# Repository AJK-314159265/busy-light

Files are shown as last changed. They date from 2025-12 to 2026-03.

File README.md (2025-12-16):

# Busy Light (Outlook → NeoPixel) — Local‑Only Project

Turn your Outlook calendar on Windows into a **busy light** driven by a single **WS2812/NeoPixel** LED over serial.  
Privacy-first: No Azure. No Graph. No Teams. **Local-only**: Outlook COM + Serial.

This repo contains everything: **Python GUI app**, **Arduino firmware**, **electronics notes**, and **3D-printed housing** guidelines.

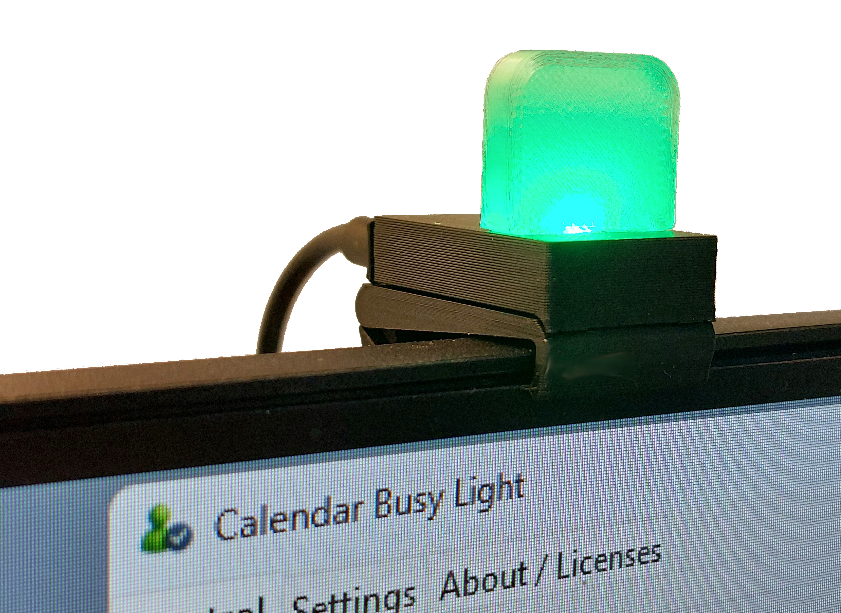
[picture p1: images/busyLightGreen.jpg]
BusyLightGreen


## Highlights

- **Windows Python GUI** reads your **local Outlook** calendar via COM
- **Arduino NeoPixel** firmware accepts `R G B` commands over serial
- **Heartbeat auto‑off**: light turns off if host goes away (no `PING`)
- **Configurable colors**, brightness, fade, blink, working hours
- **Manual mode** + **Quick test** buttons for instant checks
- **3D-printable housing** STEP files and printing suggestions

> Privacy by design: no cloud tokens, no tenant approval, no Graph calls—just your local Outlook app and a serial cable.

## Repository Structure

```text
.
├─ arduino/
│  ├─ busylight/busylight.ino # firmware for WS2812/NeoPixel
│  └─ README.md                               # Arduino-specific docs
├─ python/
│  ├─ assets/                                 # icons images
│  ├─ calendar_busy_light.py                  # main GUI app
│  └─ README.md                               # Python-specific docs
├─ hardware/
│  └─ README.md                               # (optional) detailed wiring notes
├─ housing/
│  ├─ step/                                   # STEP files
│  │  ├─ Light_Guide.step
│  │  ├─ Mounting_bracket.step
│  │  ├─ PCB_case_usb_c.step
│  │  ├─ PCB_case_back_c.step
│  │  ├─ PCB_case_micro_usb.step
│  │  └─ PCB_case_back_micro_usb.step
│  └─ README.md                               # printer settings & assembly
├─ images/
├─ LICENSE.md
└─ README.md                                  # ← this file
```

## System Overview

```text
Outlook (Windows) ──COM──► Python GUI ──Serial(115200)──► Arduino ──► NeoPixel LED
                                 ▲             │
                                 └── Heartbeat ┘  (PING/PONG; auto‑off on timeout)
```

### Status Mapping (default)

| Calendar status | LED behavior (configurable) |
| --- | --- |
| **Busy / Tentative** | Red |
| **Upcoming Busy** (N min before) | Blinking orange |
| **OOF** | Off |
| **Free / Working Elsewhere** | Green |

Everything is configurable in the GUI and saved to JSON.

## Electronics

The electronics are based on a **Pro Micro — 5 V / 16 MHz board** with a single **WS2812B** addressable RGB LED mounted on the back.

- 1× **Pro Micro — 5 V / 16 MHz** (ATmega32U4)
- 1× **WS2812B** addressable RGB LED (single LED)
- 1 × USB-C or Micro-USB cable (depending on the USB connector type of the selected Pro Micro board)

> See [**./hardware/README.md**](./hardware/README.md) for full details.

## Arduino Firmware

- File: [./arduino/busylight/busylight.ino](./arduino/busylight/busylight.ino)
- Library: **Adafruit NeoPixel** (via Library Manager)
- Baud: **115200**

### Supported Commands

- Color: `255 0 0` / `RGB 0 255 0` / `#FF8000`
- Utility: `OFF`, `TEST`
- Heartbeat: `PING` → replies `PONG`
- Watchdog config: `HBEN 0/1`, `HBTO <ms>`, `HBRST`, `STAT?`

On boot, the LED briefly blinks gray to show the firmware is running.  
If **no `PING`** is received for the configured timeout, the LED turns **off** automatically.

> See [**./arduino/README.md**](./arduino/README.md) for full details.

## Python GUI App

- File: [./python/calendar_busy_light.py](./python/calendar_busy_light.py)
- Requires: `pywin32`, `pyserial`

  ```bash
  pip install pywin32 pyserial
  ```

- Run:

  ```bash
  pythonw.exe python/calendar_busy_light.py
  ```

> See [**./windows_startup_python_guide.md**](./windows_startup_python_guide.md) for details on how to configure Windows 11 to automatically run a the Python application at startup.

### Key Features

- **Auto/Manual** mode toggle
- **Color scheme** pickers (Busy, Upcoming, Free, OOF, Unknown)
- **Brightness** (0–100%), **Fade** (ms)
- **Upcoming window** (min), **Past grace** (min)
- **Ignore subjects** (e.g., `lunch; focus; reminder`)
- **Working hours** + out‑of‑hours status behavior
- **Progress bar** and **countdown** to start/end
- **Heartbeat & ACK** (enable, interval, expect ACK, timeout)
- **Serial auto‑reconnect** and **Quick test** buttons
- **JSON settings** persisted (no registry edits)

> See [**./python/README.md**](./python/README.md) for full details.

## Housing (3D‑Printed)

The STEP files are located in the 'housing/step/' directory:

- Light_Guide.step - Translucent cap above the NeoPixel
- Mounting_bracket.step - Monitor mounting bracket
- PCB_case.step - Enclosure for the Pro Micro board with the single LED
- PCB_case_back.step - Back cover of the enclosure with slots for the USB connector

> See [**./housing/README.md**](./housing/README.md) for full details.

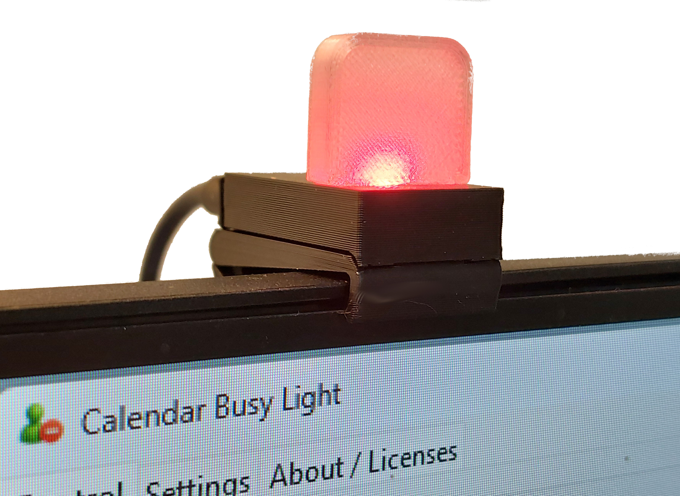
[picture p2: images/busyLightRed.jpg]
BusyLightRed


### Assembly Tips

1. Attach the LED to the back of the main PCB.
2. Route the D4, GND, and 5V wires to the LED PCB, keeping the wires as short as possible.
3. Slide the PCB into the **PCB case** with the LED facing the light opening.
4. Press-fit the **PCB case back** (back cover) over the USB plug.
5. Slide the PCB case assembly onto the mounting bracket.
6. Press-fit the **Light Guide** (diffuser) on top of the enclosure.
7. Plug in the USB cable and verify operation using the Python **Quick Test**.

See [**./hardware/README.md**](./hardware/README.md) and [**./housing/README.md**](./housing/README.md) for full details.

## Quick Start (End‑to‑End)

1. **Flash Arduino** with `NeoPixelBusyLight.ino` and verify via Serial Monitor:
   - `TEST` cycles colors, `PING` → `PONG`.
2. **Run Python app**, pick your **COM port** in *Settings → Serial*, and **Save settings**.
3. Click **Manual → Free** to verify LEDs.
4. Switch to **Auto**: your Outlook calendar should now drive the light.

## Troubleshooting

- **No light but PONG works**:
  - Check **Brightness > 0%**, **Color scheme** for current state, and **Out‑of‑hours** behavior.
- **No serial**: ensure only one app owns the COM port (close Serial Monitor).
- **Blink looks dim**: reduce **Fade** (ms) or set to **0** for hard edges.
- **Turns off randomly**: heartbeat watchdog timed out—either increase `HBTO` (firmware) or ensure the Python heartbeat interval is smaller than the timeout.

## License

This project is released as open-source software under the [MIT License](../LICENSE.md), Copyright (c) 2025 Allan Juhl Kristensen

The software is provided “as is,” without any express or implied warranty.

## Credits

- Adafruit NeoPixel library
- `pywin32`, `pyserial`

Happy making! 🎉

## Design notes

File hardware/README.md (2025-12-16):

# Busy Light Electronics

The Busy Light hardware is based on a **Pro Micro (ATmega32U4)**. The USB transceiver is integrated into the ATmega32U4, so the board provides native USB connectivity without the need for external interface components. The Pro Micro is available in both 3.3 V and 5 V variants; for this project, the **5 V / 16 MHz** version must be used.

Please note that many Pro Micro clones are available on the market. Ensure that the selected board matches the required enclosure dimensions of about **36 × 18 mm**.

## Electronics

### Bill of Materials (BOM)

- 1× **Pro Micro — 5 V / 16 MHz** (ATmega32U4)
- 1× **WS2812B** addressable RGB LED (single LED)
- 1 × USB-C or Micro-USB cable (depending on the USB connector type of the selected Pro Micro board)

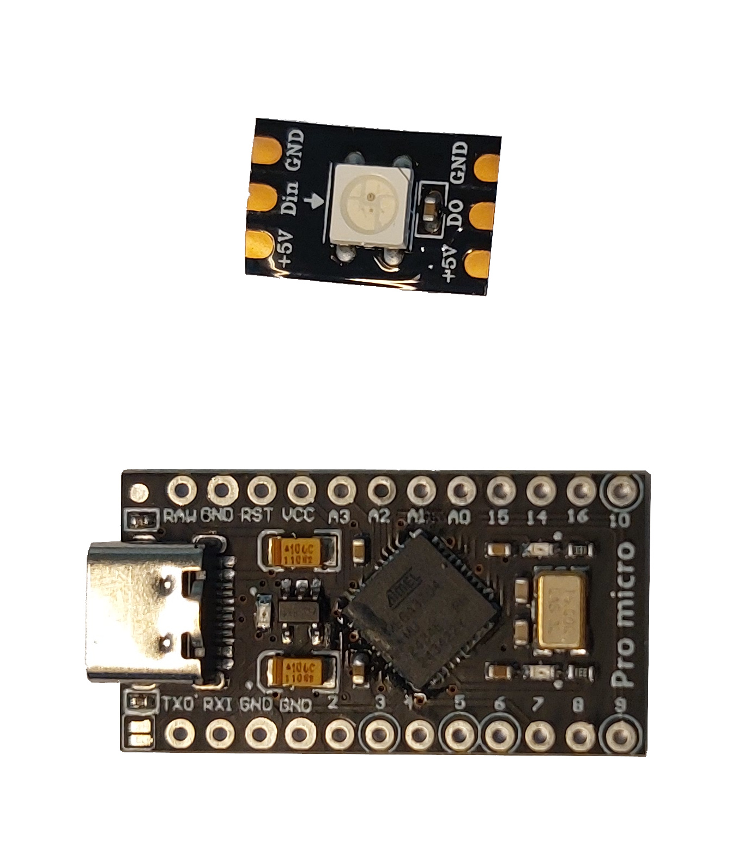
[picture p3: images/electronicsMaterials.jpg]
Materials


### Wiring (single LED)

```text
Pro Micro 5V  ──► WS2812B LED 5V
Pro Micro GND ──► WS2812B LED GND
Pro Micro D4  ──► WS2812B LED DIN
```

- Make sure the Pro Micro D4 gos to WS2812B LED **DIN** and not to WS2812B LED **DO**.
- Keep **GND common** between the Pro Micro and the LED.
- Data pin default in the firmware is **D4**; you can change it in the sketch if needed.
- With **~15 mm** data wire and **one LED**, direct wiring is fine.
- A single WS2812 at full white draws **≤60 mA** - USB can easily supply that.

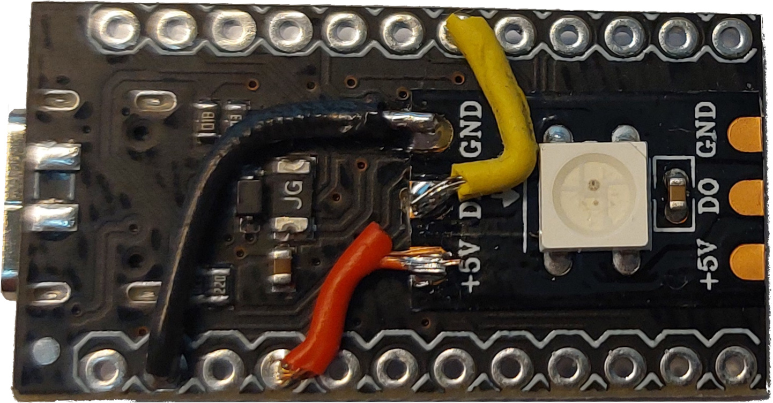
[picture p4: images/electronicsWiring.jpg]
Wiring


## Firmware Notes (Arduino)

For information on the Firmware see: [../arduino/README.md](../arduino/README.md)

## Reference & Datasheets

- [Pro Micro pinout](https://salt.tikicdn.com/ts/product/43/26/b9/10e6217f0be0510c92a05691e59fac0f.png)
- [ATmega32U4 datasheet](https://ww1.microchip.com/downloads/en/DeviceDoc/Atmel-7766-8-bit-AVR-ATmega16U4-32U4_Datasheet.pdf)
- [Pro Micro Schematic](https://cdn.sparkfun.com/datasheets/Dev/Arduino/Boards/Pro_Micro_v13b.pdf)

## License Information

This project is released as open-source software under the [MIT License](../LICENSE.md), Copyright (c) 2025 Allan Juhl Kristensen

The software is provided “as is,” without any express or implied warranty.

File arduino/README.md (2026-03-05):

# NeoPixel Busy Light (Serial + Heartbeat Auto-Off)

A tiny Arduino firmware that turns a single **WS2812 / NeoPixel** LED into a presence/busy indicator controllable over **serial**.

- Accepts simple commands like `255 0 0`, `RGB 0 255 0`, `#FF8000`, `OFF`, `TEST`.
- Responds to `PING` with `PONG` (for host health checks).
- **Auto-off** if no heartbeat (`PING`) is received for a configurable timeout.

> ⚠️ Note: Some call these LEDs “WLED”, but this sketch is for **WS2812/NeoPixel** hardware using the **Adafruit NeoPixel** library—not the WLED firmware project.

## Features

- Simple serial protocol (human-readable).
- Heartbeat watchdog: turns LED off if host disappears.
- Built-in test pattern.
- Works with any board supported by Adafruit NeoPixel (Uno, Nano, Leonardo, etc.).
- Pairs nicely with a Python GUI / status app (e.g., calendar/Teams presence).

## Hardware

For information on the Hardware see: [../hardware/README.md](../hardware/README.md)

## Getting Started (one-time setup)

1. **Install Arduino IDE** (latest).
2. **Install library**: *Tools → Manage Libraries…* → search **“Adafruit NeoPixel”** → Install.
3. Go to **File → Preferences**
4. In “**Additional Boards Manager URLs**”, add this URL (add a comma if others already exist):

   ```txt
   https://raw.githubusercontent.com/sparkfun/Arduino_Boards/master/IDE_Board_Manager/package_sparkfun_index.json
   ```

5. Click OK
6. Go to Tools → Board → Boards Manager…
7. Search for “SparkFun AVR Boards”
8. Click Install

## Select the correct board every time

1. Plug the board into USB
2. In Arduino IDE, select:
   - **Tools → Board → SparkFun AVR Boards → SparkFun Pro Micro**
   - **Tools → Processor → ATmega32U4 (5V, 16MHz)** 
   - **Tools → Port** → select the COM port that appears when you plug in the board

   > ⚠️ **Important:** Never change **Processor** to 3.3V/8MHz for these boards – that’s what breaks USB.

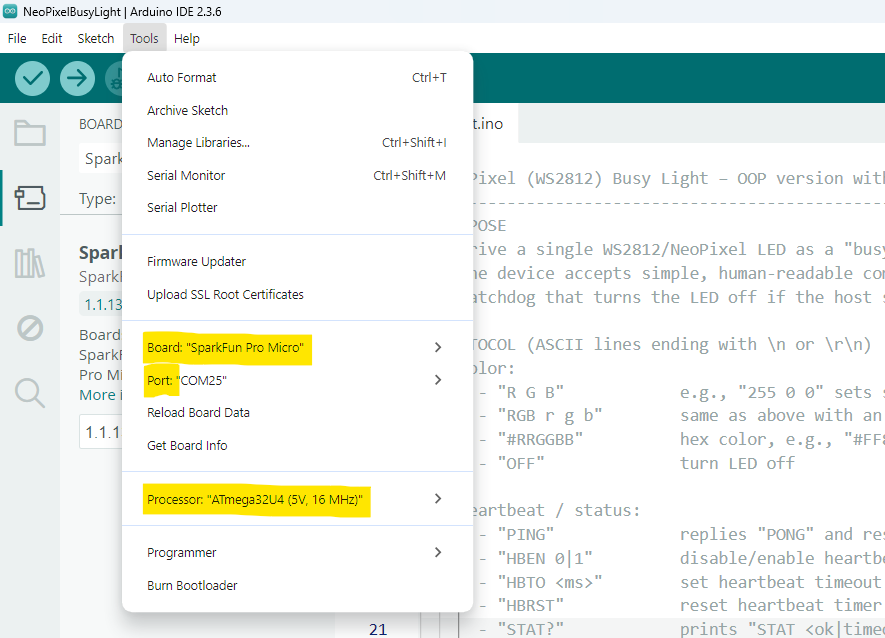
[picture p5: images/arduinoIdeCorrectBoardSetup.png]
Correct Board Setup
   

3. **Open** the sketch (`busylight.ino`) in Arduino IDE.
4. (Optional) Edit these lines if needed:

   ```cpp
   #define LED_PIN    4        // data pin to your NeoPixel
   #define NUM_LEDS   1        // number of LEDs in your strip
   #define BAUD       115200   // must match your host app
   // Heartbeat defaults:
   #define HB_DEFAULT_ENABLED     1
   #define HB_DEFAULT_TIMEOUT_MS  25000UL
   ```

5. Click Upload (the right-arrow button)
6. Wait for “Done uploading.” at the bottom
7. Open **Serial Monitor** @ **115200** and try:
   - `TEST` → cycles colors  
   - `255 255 255` → white  
   - `PING` → prints `PONG`

## Serial Protocol

| Command | Description | Example | Response |
|---|---|---|---|
| `R G B` | Set color (0–255 per channel) | `255 0 0` | – |
| `RGB r g b` | Same as above with `RGB` prefix | `RGB 0 255 0` | – |
| `#RRGGBB` | Hex color | `#FF8000` | – |
| `OFF` | Turn LED off | `OFF` | – |
| `TEST` | Cycle R→G→B→White→Off | `TEST` | – |
| `PING` | Heartbeat ping | `PING` | `PONG` |
| `HBEN 0/1`  | Disable/enable heartbeat watchdog | `HBEN 1` | `HBEN=1` |
| `HBEN?` | Report heartbeat watchdog disable/enable status | `HBEN?` | `HBEN=1` |
| `HBTO <ms>` | Set heartbeat timeout (milliseconds) | `HBTO 25000` | `HBTO=25000` |
| `HBRST` | Reset heartbeat timer | `HBRST` | `HBRST=OK` |
| `STAT?` | Report status & current RGB | `STAT?` | `STAT=OK; RGB=0 0 0` |
| `VER?` | Report firmware version and build date/time | `VER?` | `VER=1.0.0; BUILD=2026-01-05 22:03:00` |

**Behavior:**  
If `HBEN` is on (default) and **no `PING`** arrives within `HBTO` ms, the LED is **forced OFF** until a new `PING` (or color command) is received.

## Example Sessions

**Manual testing in Serial Monitor:**

```txt
> TEST
> 255 0 0
> 0 255 0
> #0000FF
> OFF
> PING
PONG
> STAT?
STAT ok RGB 0 0 0
```

**Host heartbeat rhythm**  
If your host sends `PING` every 10 s, set timeout to something like 25 s:

```txt
> HBTO 25000
HBTO=25000
> HBEN 1
HBEN=1
```

## Integrating with a Host App

- Open the COM port at **115200** baud.
- Send color lines as ASCII with a trailing newline, e.g.:

```txt
  "255 128 0\n"
  "PING\n"
```

- If you enable ACK checking in the host, read lines and look for **`PONG`**.
- Keep your heartbeat **interval < timeout** (e.g., interval 10 s, timeout 25 s).

---

## Troubleshooting

- **No light at all**
  - Verify 5V/GND, data pin, and that the **NeoPixel library** is installed.
  - Try `TEST` in Serial Monitor.
  - Some boards need a brief delay after `strip.begin()` (already included).

- **Random flicker / wrong colors**
  - Ensure **GND is shared**.
  - Prefer short wires; for long runs use a **level shifter** and series resistor on data.

- **Turns off unexpectedly**
  - Heartbeat watchdog is active; either increase `HBTO` or make sure your host sends `PING` periodically, or `HBEN 0` to disable.

- **Host can’t open COM port**
  - Close Serial Monitor and any other app using the port. Only one process can own it.

## Performance Notes

- This sketch updates **one LED** instantly; for many LEDs, you can raise `NUM_LEDS`.
- The watchdog only blanks the LEDs; it doesn’t reset the MCU.

## License

[MIT License](./../LICENSE.md), Copyright (c) 2025 Allan Juhl Kristensen

## Acknowledgements

- [Adafruit NeoPixel](https://github.com/adafruit/Adafruit_NeoPixel)

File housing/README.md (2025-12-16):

# BusyLight – 3D Printed Enclosure & Assembly Guide

This README describes how to 3D print and assemble the BusyLight enclosure, including recommended printer settings and step-by-step assembly instructions.

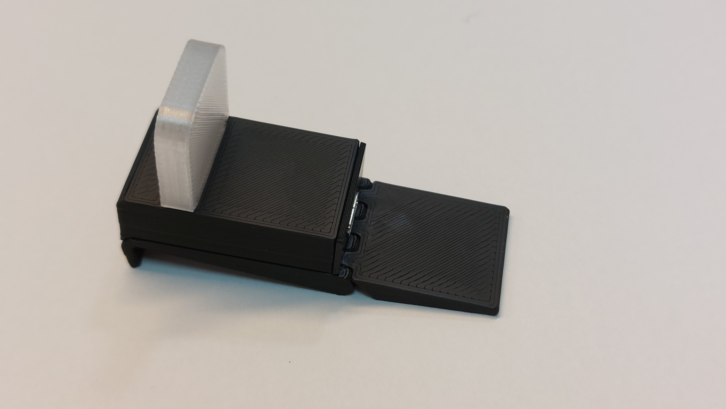
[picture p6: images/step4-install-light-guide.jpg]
Assembled BusyLight


## Printed Parts

You will need to print the following parts:

- [**Mounting Bracket**](./step/Mounting_bracket.step)
- [**Light Guide**](./step/Light_Guide.step)
- [**PCB Case**](./step/PCB_case_micro_usb.step)
- [**PCB Case Back**](./step/PCB_case_back_micro_usb.step)
- [**PCB Case**](./step/PCB_case_usb_c.step)
- [**PCB Case Back**](./step/PCB_case_back_usb_c.step)

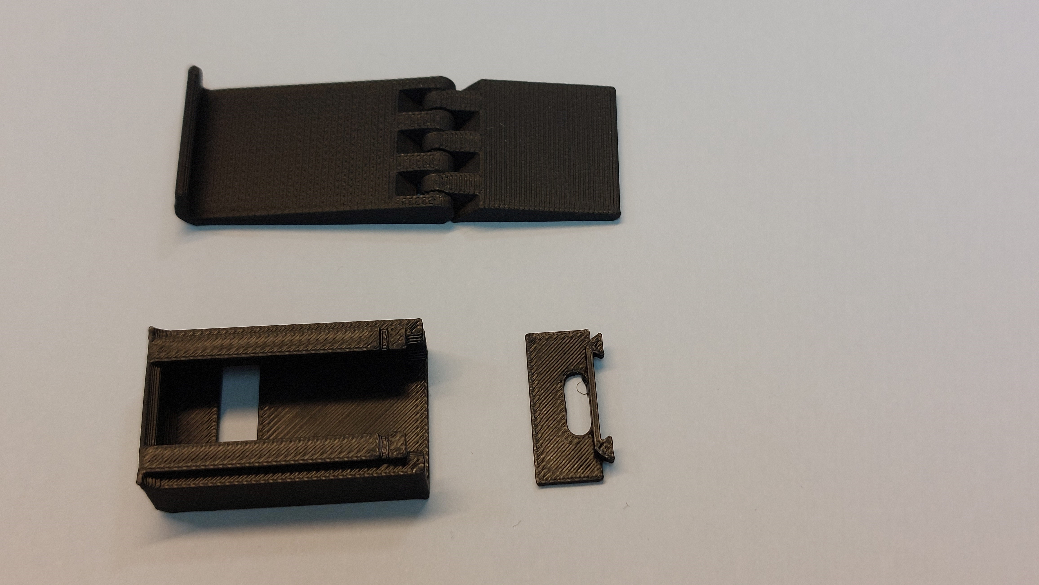
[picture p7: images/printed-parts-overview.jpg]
All Printed Parts


## Printer Settings

### General Settings (All Parts Except Light Guide)

Use your slicer’s **standard / default profile** for all parts except the Light Guide. For example:

- **Layer height:** ~0.20 mm
- **Perimeters (walls):** 2–3  
- **Infill:** 15–25%  
- **Top / bottom layers:** 3–5  

Adjust if needed based on your printer and filament.

### Special Settings for the Light Guide (Diffuser)

For best light diffusion use Translucent filament:

- **Part:** `Light Guide`  
- **Infill:** **100%**  
- All other settings can follow your standard profile.

## Required Hardware

- 1 × **BusyLight PCB** (with LED and USB plug)
- 1 × **PCB Case** (3D printed)
- 1 × **PCB Case Back** / back cover (3D printed)
- 1 × **Mounting Bracket** (3D printed)
- 1 × **Light Guide** / diffuser (3D printed)

No screws or glue are required; all parts are designed as **press-fit**.

## Assembly Instructions

Follow these steps after printing and cleaning up all parts (remove any stringing or support material):

### 1. Attach the PCB Case Back

Press-fit the **PCB Case Back** (back cover) onto the **PCB Case**, guiding it over the **USB plug** so that the plug exits through the opening.

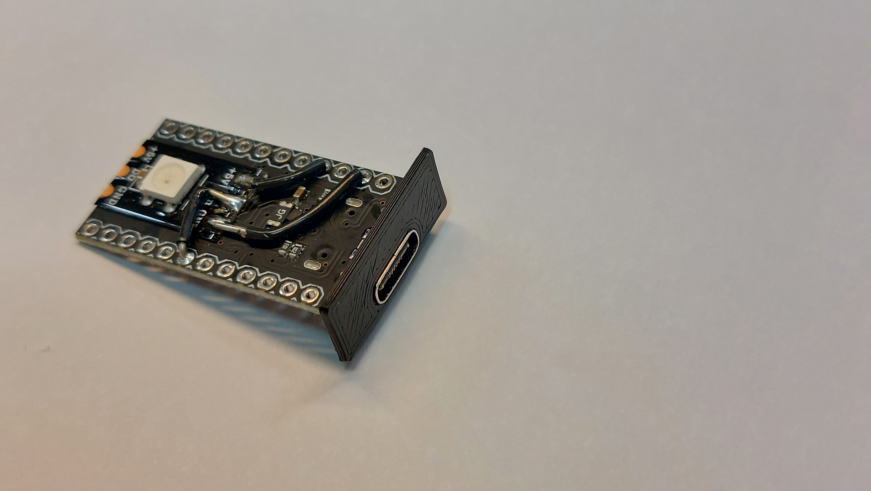
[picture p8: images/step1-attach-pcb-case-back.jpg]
Step 1 – Press-Fit PCB Case Back


### 2. Insert the PCB into the PCB Case

Slide the **PCB** into the **PCB Case** with the **LED facing the light opening** in the case.

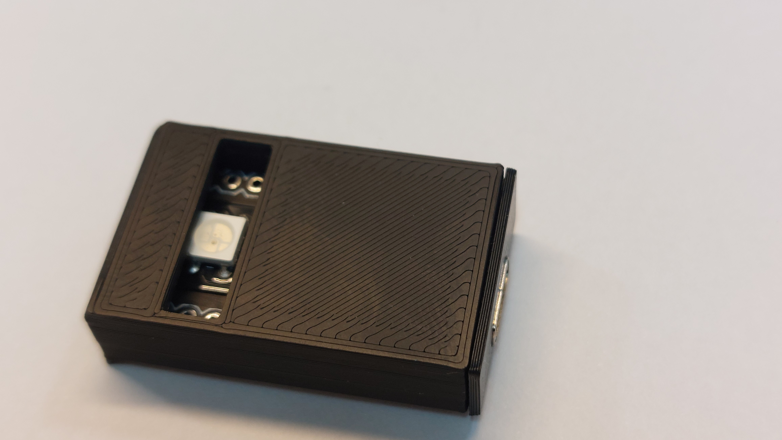
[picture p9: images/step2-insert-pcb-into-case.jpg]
Step 2 – Insert PCB into Case


### 3. Mount the PCB Assembly onto the Bracket

Slide the **assembled PCB Case** (with back cover installed) onto the **Mounting Bracket** until it clicks or feels firmly seated.

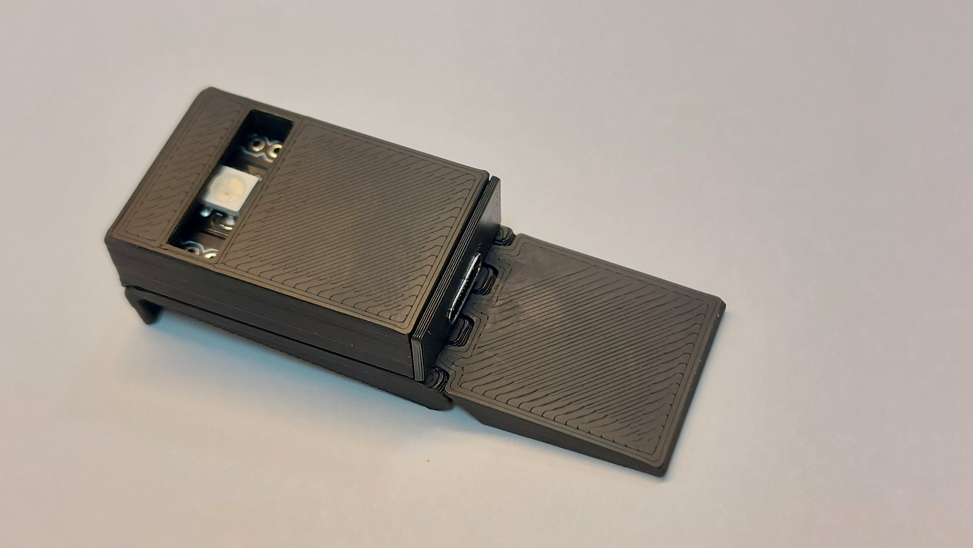
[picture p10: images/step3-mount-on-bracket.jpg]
Step 3 – Slide Assembly onto Bracket


### 4. Install the Light Guide (Diffuser)

Press-fit the **Light Guide** on top of the enclosure, over the LED opening, until it sits flush and secure.

Step 4 – Press-Fit Light Guide

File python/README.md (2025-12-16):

# Calendar Busy Light — Python GUI (Outlook → LED)

A Windows Python app that turns your **Outlook desktop calendar** into a **busy light** for an RGB LED.  
**No Azure, no Graph, no Teams.** Local-only via Outlook **COM** and **Serial**.

Pairs with the included Arduino **NeoPixel** sketch (or any MCU that accepts `R G B\n`).

## Features

- **Auto mode (Outlook → status → LED)**  
  - `Busy`/`Tentative` → **busy** (red)  
  - **Upcoming busy** (N minutes before start) → **blinking orange**  
  - `OOF` → **off** (configurable)  
  - `Free`/`WorkingElsewhere` → **free** (green)
- **Manual mode (status)**  
  Pick **Free / Busy / Upcoming busy (blinks) / OOF** directly in the UI.
- **Quick overrides**  
  - **Free until meeting ends** (for early finishes)  
  - **Busy for N minutes** (default 15 min)  
  *Upcoming-busy blink is never suppressed by overrides.*
- **Dynamic taskbar/window icon (files-only)**  
  Per-status **.ico/.png** files for **busy / upcoming / free / oof / unknown**.  
  (No auto-color generation; you control the icons.)
- **Color scheme editor**  
  Configure RGB for **busy / upcoming_busy / free / oof / unknown**.
- **Brightness slider** (0–100%, integer readout) + **smooth fade** transitions.
- **Meeting context at a glance**  
  Big status banner, **countdown** (to **start** during upcoming, to **end** during busy), **progress bar**, next/current meeting lines.
- **Ignore filters**  
  Skip calendar items whose subject contains any of your `;`-separated tokens (e.g. `lunch; focus; reminder`).
- **Working-hours model**  
  Weekdays-only toggle, start/end time, and **out-of-hours status** (e.g. `oof` to turn LED off after hours).
- **Heartbeat & ACK** to the device (`PING`/`PONG`) with auto-reconnect.
- **Serial auto-reconnect** when USB is unplugged/replugged.
- **Logging to file** (rotating), with **Open log file / Open logs folder** buttons.
- **About / Licenses** tab  
  Show MIT license + third-party attributions (e.g., Noun Project CC BY 3.0 icon credit).

## Requirements

- **Windows** with **Outlook desktop (classic)** installed and signed in (uses COM).
- **Python 3.9+** (tested with 3.13).
- Install dependencies:

  ```bash
  pip install pywin32 pyserial
  ```

- Optional hardware:  
  An Arduino/Pro Micro (ATmega32U4) with a **WS2812/NeoPixel** LED and the provided sketch, or any MCU that accepts ASCII `R G B\n` at **115200** baud.

> No cloud permissions. The app reads your **local Outlook calendar** only.

## Quick start

1. Clone/download the repo.
2. Install dependencies:

   ```bash
   pip install pywin32 pyserial
   ```

3. Run the GUI (no console):

   ```bash
   pythonw.exe calendar_busy_light.py
   ```

4. In **Settings → Serial / Hardware**, set your **COM port** and click **Save settings**.
5. On **Control**, switch to **Manual**, pick **Free/Busy/Upcoming/OOF** to test the LED.
6. Switch to **Auto** to let Outlook drive the light.

> Config and logs live in **`%APPDATA%\CalendarBusyLight\`** and persist across restarts.

## How it works

- The app queries Outlook via **pywin32 COM** using a time-window Restrict filter around “now”.
- It derives a **calendar status**:
  - Overlaps now and `Busy/Tentative` → **busy**
  - Starts within **Upcoming busy (N minutes)** → **upcoming_busy** (blink)
  - Overlaps now and `OOF` → **oof**
  - Otherwise → **free**
- Status maps to your **configured RGB**, then the app sends `R G B\n` to the serial device.  
  Heartbeat sends `PING\n`; if **Expect ACK** is enabled, it looks for `PONG`.
- **Brightness** (0–100%) and **fade (ms)** are applied in software.

## UI guide

### Control

- **Mode**: **Auto** (Outlook) / **Manual** (pick status: free/busy/upcoming/oof)
- **Quick override**:  
  - **Free until meeting end**  
  - **Busy for *N* minutes** (configurable default)  
  Shows a live **override countdown**.
- **Status banner** (FREE / BUSY / UPCOMING / OOF) + big colored indicator.
- **Current / Next** meeting lines and **countdown**.
- **Progress bar**:  
  - Fills toward **start** when upcoming  
  - Fills toward **end** when busy
- **Preview circle** mirrors the LED output.

### Settings

- **Serial / Hardware**: COM port, baud, **Simulate**, retry seconds.
- **Heartbeat & ACK**: enable, interval, **Expect ACK**, command/response, timeout.
- **Timing**: calendar refresh (s), blink period (s), GUI tick (ms).
- **Calendar logic**: upcoming window (min), past grace (min), **Ignore subjects** (`;`-separated).
- **Working hours**: weekdays-only, start/end, **out-of-hours status** (`oof`/free/`busy`/`unknown`).
- **Appearance**: **Brightness %** (integer display), **Fade ms**.
- **Color scheme**: edit hex colors for busy / upcoming_busy / free / oof / unknown.
- **Taskbar icon (per status files)**: enable, browse/clear **.ico/.png** for each status.  
  (No auto-color generation; uses your files. `.ico` with 16/32/48/256px is recommended on Windows.)
- **Logging**: verbose calendar overview, status summary, **log color changes**, **Open log file**, **Open logs folder**.
- **Application**: choose a window icon file (fallback if no per-status icon applies).
- **Save settings** writes JSON to `%APPDATA%\CalendarBusyLight\calendar_busy_light_config.json`.

## Configuration

Path: **`%APPDATA%\CalendarBusyLight\calendar_busy_light_config.json`**

```jsonc
{
  "serial_port": "COM2",
  "baudrate": 115200,
  "simulate": false,
  "serial_retry_seconds": 5,

  "status_refresh_seconds": 15.0,
  "blink_period_seconds": 1.0,
  "gui_tick_ms": 100,

  "upcoming_busy_minutes": 5,
  "past_grace_minutes": 1,
  "ignore_subjects": "lunch; focus; reminder",

  "work_start_hour": 8, "work_start_minute": 0,
  "work_end_hour": 17,  "work_end_minute": 0,
  "weekdays_only": true,
  "out_of_hours_status": "oof",

  "verbose_calendar": false,
  "show_status_summary": true,
  "log_color_changes": true,
  "brightness_percent": 100,
  "fade_ms": 300,

  "colors": {
    "busy": [255, 0, 0],
    "upcoming_busy": [255, 128, 0],
    "free": [0, 255, 0],
    "oof": [0, 0, 0],
    "unknown": [0, 0, 0]
  },

  "heartbeat_enabled": true,
  "heartbeat_interval_seconds": 10,
  "heartbeat_expect_ack": false,
  "heartbeat_command": "PING",
  "heartbeat_response": "PONG",
  "heartbeat_timeout_ms": 500,

  "quick_override_enabled": true,
  "quick_override_default_minutes": 15,

  "app_icon_path": "",                       // fallback window icon
  "dynamic_status_icon_enabled": true,       // files-only dynamic icons
  "dynamic_status_icon_mode": "files",
  "status_icon_files": {
    "busy": "",
    "upcoming_busy": "",
    "free": "",
    "oof": "",
    "unknown": ""
  }
}
```

> Edit via the GUI when possible; manual edits are fine (the app clamps values on save).

## Logs

- Rotating log at: **`%APPDATA%\CalendarBusyLight\logs\busy_light.log`**  
  Open directly from **Settings → Logging → Open log file / Open logs folder**.

## Device protocol (reference)

- Commands: `R G B`, `RGB r g b`, `#RRGGBB`, `OFF`, `TEST`, `PING`  
- Optional heartbeat watchdog: turns LED **off** if no `PING` seen within timeout.
- Baud: **115200**. Only one program can open the COM port at a time.

## Troubleshooting

- **No light but serial is connected**  
  Check **Brightness > 0%**, **out-of-hours status**, and your **Color scheme** for the current status.
- **Manual works, Auto stays off**  
  Likely outside working hours with `out_of_hours_status = "oof"`.
- **Outlook not read**  
  Ensure Outlook desktop is running. Try toggling Outlook. Enable **Verbose calendar** in Logging.
- **Taskbar icon doesn’t switch**  
  Make sure per-status `.ico/.png` paths are set and files exist. For pinned shortcuts, unpin → run → pin.
- **Blink looks “soft”**  
  Set **Fade ms = 0** to test hard on/off edges.

## Privacy

- The app reads **only your local Outlook calendar** via COM.  
  **No network calls, no Graph/Azure, no tokens.**

## License

This project is released as open-source software under the [MIT License](./../LICENSE.md), Copyright (c) 2025 Allan Juhl Kristensen

The software is provided “as is,” without any express or implied warranty.

## Acknowledgements

- freeconvert [PNG to ICO Converter](https://www.freeconvert.com/png-to-ico)
- `pywin32` for Outlook COM access
- `pyserial` for device communication

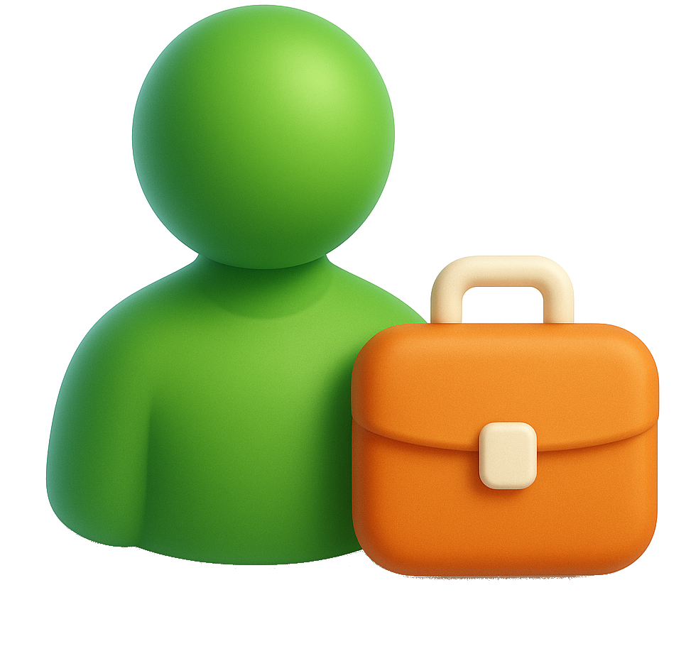
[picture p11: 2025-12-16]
python/assets/out_of_office.png

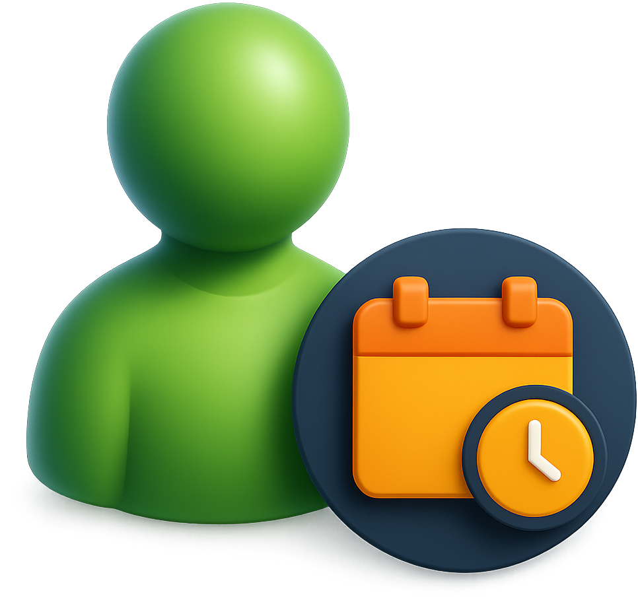
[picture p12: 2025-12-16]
python/assets/upcoming_busy.png

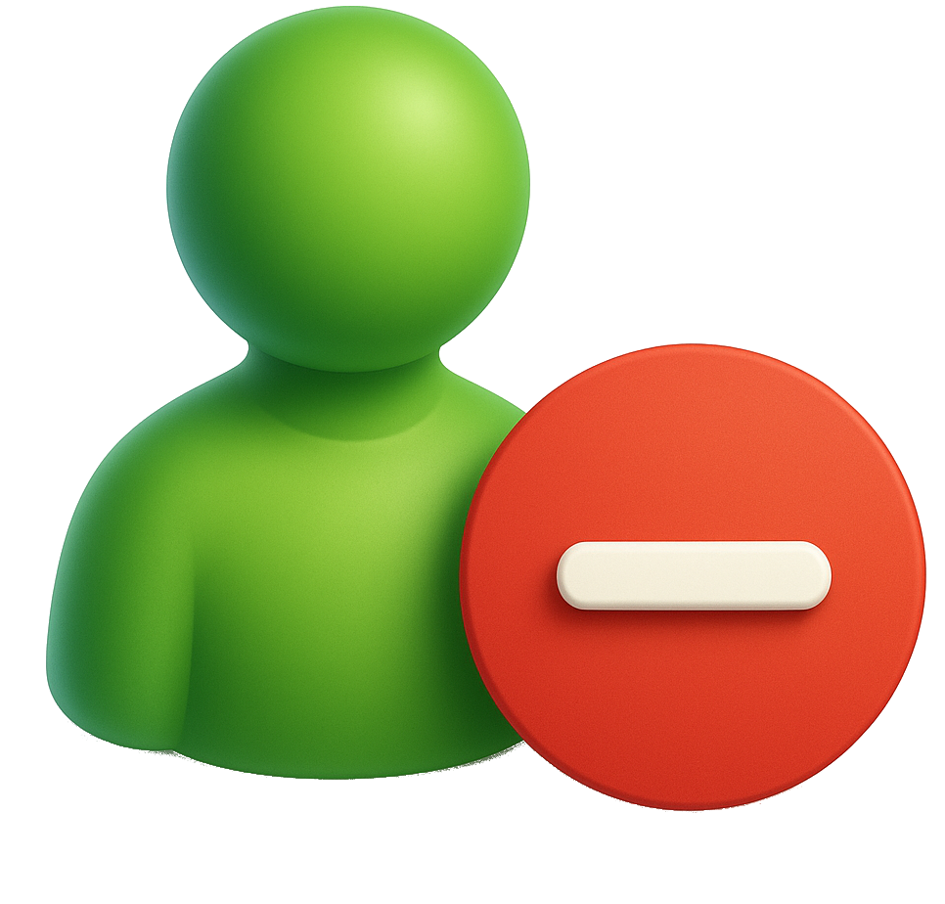
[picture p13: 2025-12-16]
python/assets/busy.png

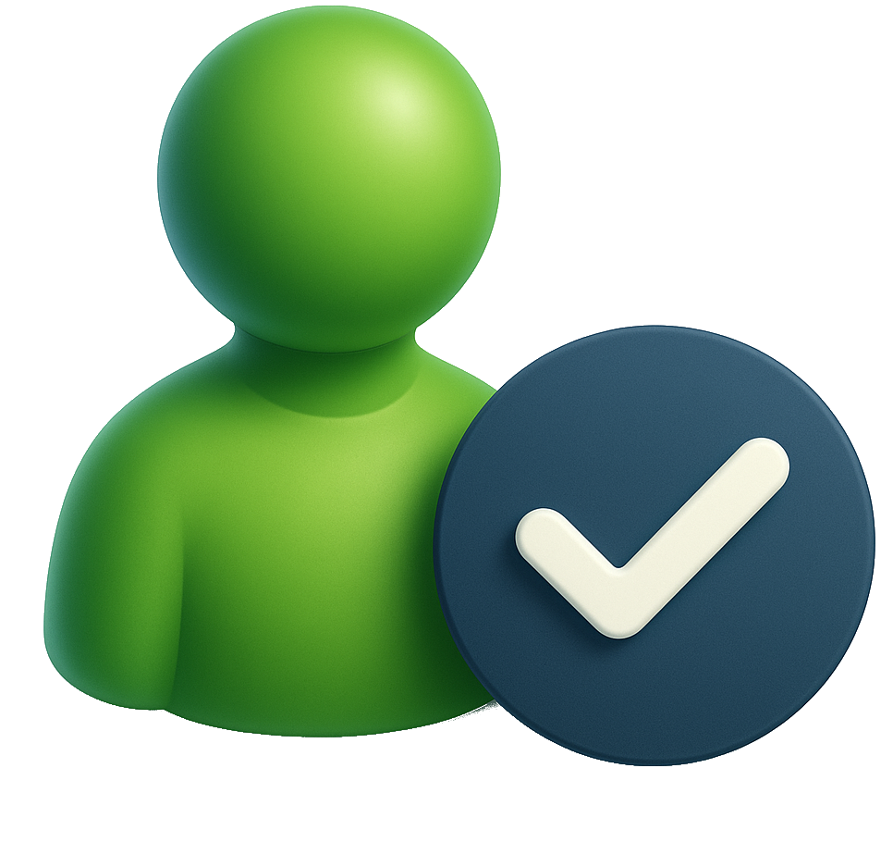
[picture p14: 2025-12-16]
python/assets/free.png

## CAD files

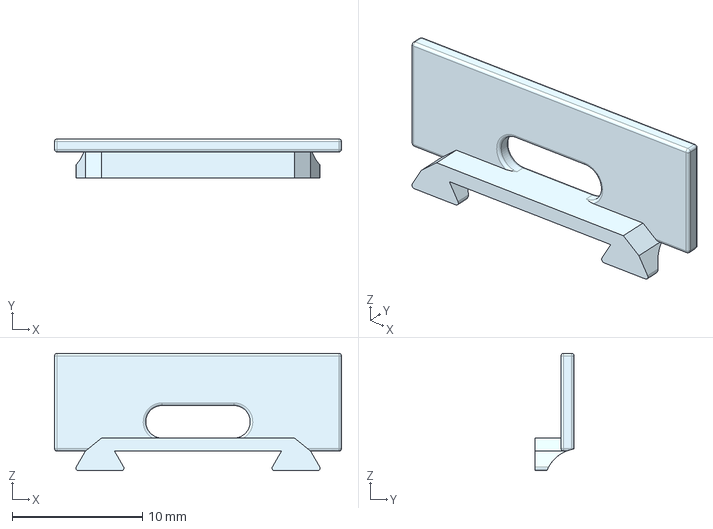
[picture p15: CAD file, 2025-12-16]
housing/step/PCB_case_back_micro_usb.step
22.0 x 3.00 x 9.00 mm

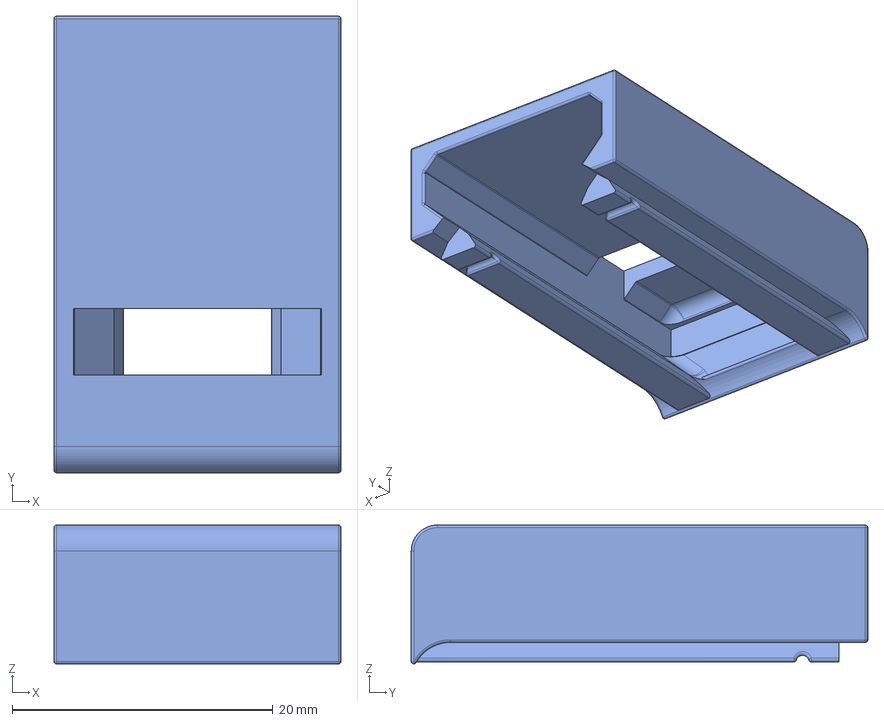
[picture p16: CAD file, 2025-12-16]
housing/step/PCB_case_usb_c.step
22.0 x 35.0 x 10.7 mm

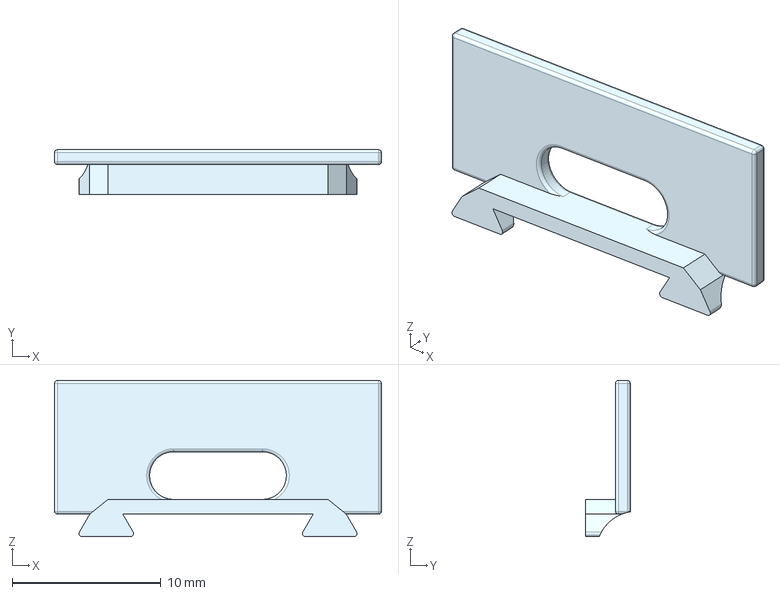
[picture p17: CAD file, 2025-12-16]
housing/step/PCB_case_back_usb_c.step
22.0 x 3.00 x 10.5 mm

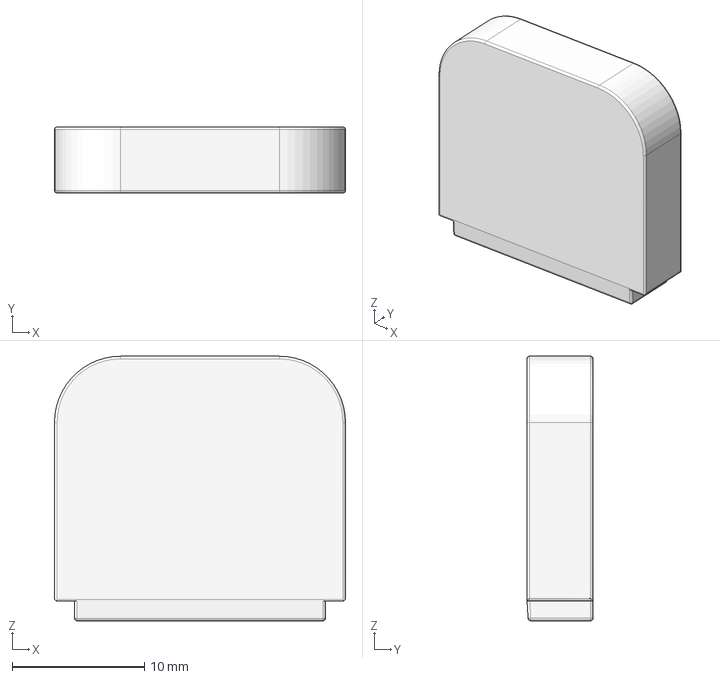
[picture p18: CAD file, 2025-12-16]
housing/step/Light_Guide.step
22.0 x 5.00 x 20.0 mm

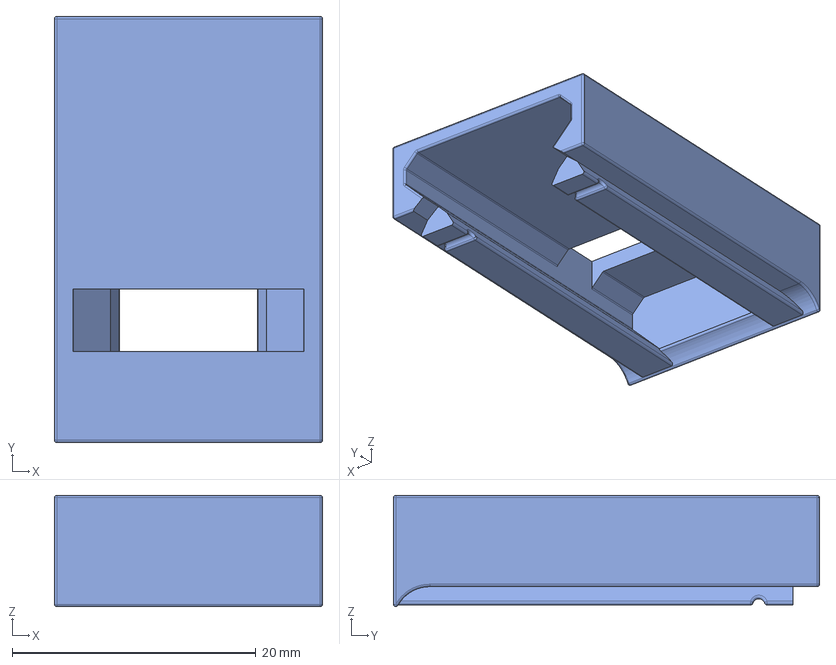
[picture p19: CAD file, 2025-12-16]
housing/step/PCB_case_micro_usb.step
22.0 x 35.0 x 9.15 mm

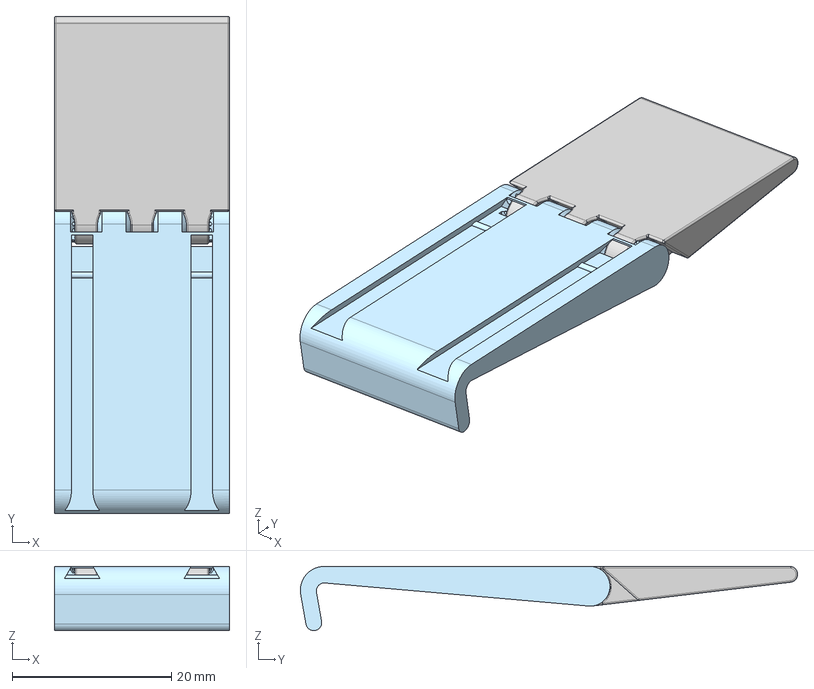
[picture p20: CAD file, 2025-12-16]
housing/step/Mounting_bracket.step
22.0 x 62.5 x 8.07 mm

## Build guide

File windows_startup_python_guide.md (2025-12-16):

# Running the Python App at Windows 11 Startup

This guide explains how to configure Windows 11 to automatically run a Python application at startup using the **Startup** folder and a **shortcut**.

In this example, we will start:

- Python interpreter: `C:\Python313\pythonw.exe`  
- Script: `C:\busy light\calendar_busy_light.py`  

You can adapt the paths to match your own installation.

## 1. Open the Startup Folder

1. Press **`Win + R`** on your keyboard to open the **Run** dialog.
2. Type:

   ```text
   shell:startup
   ```

3. Press **Enter**.  
   This opens the **Startup** folder for your user account. Any program or shortcut placed here will run automatically when you log in.

## 2. Create a Shortcut to Your Python Script

1. In the **Startup** folder, right-click on an empty area.
2. Select **New → Shortcut**.
3. In the **Type the location of the item** field, enter:

   ```text
   C:\Python313\pythonw.exe "C:\busy light\calendar_busy_light.py"
   ```

   - `pythonw.exe` runs Python without opening a console window.
   - The script path is enclosed in quotes because the folder name contains a space (`busy light`).

4. Click **Next**.
5. Enter a descriptive name for the shortcut, for example:

   ```text
   Busy Light – Calendar Script
   ```

6. Click **Finish**.

The shortcut will now appear in the **Startup** folder.

## 3. Test the Configuration

To confirm that everything works:

1. **Restart** your computer or **sign out** and sign back in.
2. After logging in, Windows should automatically run the Python script in the background via `pythonw.exe`.

If the script does not start:

- Double-check the paths in the shortcut target.
- Ensure that `pythonw.exe` exists at `C:\Python313\`.
- Verify that `calendar_busy_light.py` runs correctly when started manually.

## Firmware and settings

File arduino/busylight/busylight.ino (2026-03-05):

/*
  NeoPixel (WS2812) Busy Light – OOP version with detailed comments
  -----------------------------------------------------------------
  PURPOSE
    Drive a single WS2812/NeoPixel LED as a "busy light" controlled over Serial.
    The device accepts simple, human-readable commands and supports a heartbeat
    watchdog that turns the LED off if the host stops sending PINGs.

  PROTOCOL (ASCII lines ending with \n or \r\n)
    Color:
      - "R G B"            e.g., "255 0 0" sets solid red
      - "RGB r g b"        same as above with an "RGB" prefix
      - "#RRGGBB"          hex color, e.g., "#FF8000"
      - "OFF"              turn LED off

    Heartbeat / status:
      - "PING"             replies "PONG" and resets heartbeat timer
      - "HBEN 0|1"         disable/enable heartbeat watchdog (auto-off on timeout)
      - "HBEN?"            replies with the heartbeat watchdog disable/enable status
      - "HBTO <ms>"        set heartbeat timeout in milliseconds; min clamp = 500ms; max clamp = 86400000ms (one day)
      - "HBTO?"            replies with the heartbeat timeout in milliseconds;
      - "HBRST"            reset heartbeat timer to "now"
      - "STAT?"            prints "STAT <ok|timeout> RGB r g b"
      - "VER?"             replies with the version of the Arduino code

    Test:
      - "TEST"             cycles R→G→B→White→Off for quick verification

  ELECTRICAL / HARDWARE
    - Uses Adafruit NeoPixel library on a *single* LED by default.
    - Default data pin = D4; you can change in cfg::LED_PIN.
    - Keep GND common with the host/device.

  DESIGN
    - OOP structure with clear responsibilities:
        * NeoPixelLed      -> hardware control of the LED
        * Heartbeat        -> timeout logic for auto-off
        * SerialLineReader -> non-blocking line-based serial input
        * BusyLightApp     -> command parsing & orchestration
    - Memory-conscious: small fixed buffers, no dynamic allocation.
    - The single app instance is held as a function-local static.

  DEPENDENCIES
    - Adafruit NeoPixel (install via Arduino Library Manager)
    - Works on typical AVR boards (Uno, Nano, Leonardo/Pro Micro), and others.

  BAUD RATE
    - 115200 (match with your Python GUI/app)

  COPYRIGHT / LICENSE
    - This project is released as open-source software under the MIT License, Copyright (c) 2025 Allan Juhl Kristensen
    - The software is provided “as is,” without any express or implied warranty.
*/

#include <Arduino.h>
#include <Adafruit_NeoPixel.h>
#include <ctype.h>   // toupper
#include <string.h>  // strlen, strcmp, strncpy
#include <stdlib.h>  // strtol, atoi, atol
#include <EEPROM.h>

// Version string
constexpr const char* VERSION = "1.0.0";

// --- Workaround for Arduino's auto-prototype order ---
class BusyLightApp;            // forward-declare the class so it's a known type
static BusyLightApp& app();    // forward-declare the function, too

// ---------- Compile-time configuration (kept as constexpr, not as globals) ----------
namespace cfg {
  // NeoPixel pin and count. For a single LED, NUM_LEDS = 1.
  constexpr uint8_t  LED_PIN  = 4;
  constexpr uint16_t NUM_LEDS = 1;

  // Serial BAUD. Must match your host (e.g., Python app).
  constexpr uint32_t BAUD     = 115200;

  // Heartbeat defaults: enable auto-off and set a sensible timeout.
  constexpr bool     HB_DEFAULT_ENABLED   = true;
  constexpr uint32_t HB_DEFAULT_TIMEOUT_MS = 25000UL; // 25 seconds works well with 10s PING interval
  constexpr uint32_t HB_MIN_TIMEOUT_MS = 500UL; // clamp to a safe 0.5s minimum
  constexpr uint32_t HB_MAX_TIMEOUT_MS = 86400000UL; // One day (24*60*60*1000)
  
  // WS2812 brightness (0..255). Host can scale brightness before sending RGB;
  // KSeep the pixel at full power here.
  constexpr uint8_t  BRIGHTNESS     = 255;
}

namespace eeprom_cfg {
  constexpr int      ADDR    = 0;        // EEPROM start address
  constexpr uint16_t MAGIC   = 0xB11E;   // "B11E" = BusyLight-ish
  constexpr uint8_t  VERSION = 1;
}

// ---------- Small utility functions ----------
/* Returns true for standard whitespace characters used by our parser. */
static inline bool isSpaceC(char c) {
  return (c==' ' || c=='\t' || c=='\r' || c=='\n');
}

/* Trims leading/trailing whitespace IN PLACE and returns pointer to the first non-space. */
static char* trimInPlace(char* s) {
  while (*s && isSpaceC(*s)) s++; // skip leading space
  if (!*s) return s; // empty or all space -> return ""
  char* e = s + strlen(s) - 1; // last char
  while (e > s && isSpaceC(*e)) { *e = 0; e--; } // remove trailing space
  return s;
}

// ---------- NeoPixel driver (LED hardware abstraction) ----------
class NeoPixelLed {
public:
  /* Construct with number of LEDs and the data pin. Use GRB order @ 800kHz. */
  NeoPixelLed(uint16_t n, uint8_t pin)
  : strip_(n, pin, NEO_GRB + NEO_KHZ800), desired_{0, 0, 0}, actual_{0, 0, 0} {}

  /* Initialize the NeoPixel, set brightness, and turn it off. */
  void begin() {
    strip_.begin();
    strip_.setBrightness(cfg::BRIGHTNESS);
    showActual_();
  }

  // Force LED OFF due to heartbeat timeout without losing desired color.
  void forceOff() {
    actual_ = {0, 0, 0};
    showActual_();
  }

  // Restore actual color to desired (used when heartbeat resumes).
  void restoreDesired() {
    actual_ = desired_;
    showActual_();
  }

  /* Set the current color (0..255 per channel) and push to the LED. */
  void setRGB(uint8_t r, uint8_t g, uint8_t b) {
    desired_ = {r, g, b};
    actual_  = desired_;
    showActual_();
  }

  /* Simple power-on blink: dim gray → off, so you know the firmware is running. */
  void bootBlink() {
    delay(120);
    setRGB(24,24,24);
    delay(120);
    setRGB(0,0,0);
  }

  /* A small color cycle test for manual verification. */
  void testPattern() {
    setRGB(255,0,0);     delay(250);
    setRGB(0,255,0);     delay(250);
    setRGB(0,0,255);     delay(250);
    setRGB(255,255,255); delay(250);
    setRGB(0,0,0);       delay(200);
  }

  /* Read back the last commanded RGB (what is on the LED). */
  void getRGB(uint8_t& r, uint8_t& g, uint8_t& b) const {
    r = actual_.r; g = actual_.g; b = actual_.b;
  }

private:
  struct Rgb {
    uint8_t r;
    uint8_t g;
    uint8_t b;
  };

  void showActual_() {
    strip_.setPixelColor(0, strip_.Color(actual_.r, actual_.g, actual_.b));
    strip_.show();
  }

  Adafruit_NeoPixel strip_;
  // To keep track of the last desired color to restore actual color to desired (used when heartbeat resumes)
  Rgb desired_{0, 0, 0};
  // To keep track of the last commanded color so STAT? can report it. 
  Rgb actual_{0, 0, 0}; 
};

// ---------- Heartbeat watchdog (auto-off when host stops pinging) ----------
class Heartbeat {
public:
  /* Construct with initial enabled state and timeout in ms. */
  Heartbeat(bool enabled, uint32_t timeoutMs)
  : enabled_(enabled), timeoutMs_(timeoutMs),
    lastPingMs_(0), timedOut_(false) {}

  /* Start or restart the timer. Call once in setup(). */
  void begin() {
    loadFromEeprom_();     // override defaults if valid
    reset();
  }

  /* Call when a PING command is received; marks us as alive. */
  void ping() {
    reset();
  }

  /* Reset: timer restarts, not timed-out. */
  void reset() { 
    lastPingMs_ = millis();
    timedOut_ = false; }

  /* Enable/disable the watchdog at runtime (HBEN). */
  void setEnabled(bool en){
    if (enabled_ == en) return;
    enabled_ = en;
    if (!enabled_) timedOut_ = false;
    saveToEeprom_();
  }
  bool enabled() const { return enabled_; }
  uint32_t timeoutMs() const { return timeoutMs_; }

  /* Configure timeout (HBTO). */
  void setTimeout(uint32_t ms) {
    if (ms < cfg::HB_MIN_TIMEOUT_MS) ms = cfg::HB_MIN_TIMEOUT_MS;
    if (ms > cfg::HB_MAX_TIMEOUT_MS) ms = cfg::HB_MAX_TIMEOUT_MS;
    if (timeoutMs_ == ms) return;
    timeoutMs_ = ms;
    saveToEeprom_();
  }
  uint32_t timeout() const { return timeoutMs_; }

  void resetToDefaultsAndPersist() {
      enabled_   = cfg::HB_DEFAULT_ENABLED;
      timeoutMs_ = cfg::HB_DEFAULT_TIMEOUT_MS;
      timedOut_  = false;
      lastPingMs_ = millis();
      saveToEeprom_();
    }

  /*
    Periodic update. Returns true exactly once when transition into "timed out".
    The caller (app) can use this to perform an action (e.g., force LED off).
    If heartbeat remains disabled, update() does nothing.
  */
  bool update() {
    if (!enabled_) return false;
    const uint32_t now = millis();
    if (!timedOut_ && (now - lastPingMs_ > timeoutMs_)) {
      timedOut_ = true;
      return true; // edge: just timed out this call
    }
    return false;  // either still OK or already timed-out
  }

  bool isTimedOut() const { return timedOut_; }

private:
  struct Persist {
    uint16_t magic;
    uint8_t  version;
    uint8_t  enabled;     // 0/1
    uint32_t timeoutMs;   // heartbeat timeout
    uint8_t  checksum;    // simple checksum
  };

  void loadFromEeprom_() {
    Persist p{};
    EEPROM.get(eeprom_cfg::ADDR, p);

    if (p.magic != eeprom_cfg::MAGIC) return;
    if (p.version != eeprom_cfg::VERSION) return;

    const uint8_t cs = checksum(p);
    if (cs != p.checksum) return;

    enabled_ = (p.enabled != 0);
    timeoutMs_ = p.timeoutMs;

    if (timeoutMs_ < cfg::HB_MIN_TIMEOUT_MS) timeoutMs_ = cfg::HB_MIN_TIMEOUT_MS;
  }

  void saveToEeprom_() const {
    Persist p{};
    p.magic     = eeprom_cfg::MAGIC;
    p.version   = eeprom_cfg::VERSION;
    p.enabled   = enabled_ ? 1 : 0;
    p.timeoutMs = timeoutMs_;
    p.checksum  = checksum(p);

    // EEPROM.put uses update semantics (only writes changed bytes)
    EEPROM.put(eeprom_cfg::ADDR, p);
  }

  uint8_t checksum(const Persist& p) {
    // Simple XOR checksum over all bytes except checksum itself
    const uint8_t* b = reinterpret_cast<const uint8_t*>(&p);
    uint8_t x = 0;
    for (size_t i = 0; i < sizeof(Persist) - 1; ++i) {
      x ^= b[i];
    }
    return x;
  }

  bool     enabled_;
  uint32_t timeoutMs_;
  uint32_t lastPingMs_;
  bool     timedOut_;
};

// ---------- Non-blocking, line-based serial reader ----------
class SerialLineReader {
public:
  SerialLineReader(): len_(0) { buf_[0] = 0; }

  /*
    Read bytes from the given Stream (e.g., Serial) without blocking.
    Accumulates into an internal buffer until a newline (\n or \r) is seen.
    When a full line is ready, returns true and sets lineOut to point to the buffer.
    The line is NUL-terminated and safe to parse. The next call starts a new line.
    If the line would overflow the buffer, it's discarded (len reset to 0).
  */
  bool readLine(Stream& s, const char*& lineOut) {
    while (s.available() > 0) {
      const char c = (char)s.read();
      if (c == '\n' || c == '\r') {
        if (len_ > 0) {
          buf_[len_] = 0; // terminate the string
          lineOut = buf_;
          len_ = 0;
          return true;
        }
        // ignore empty CR/LF sequences
      } else {
        if (len_ < (sizeof(buf_) - 1)) {
          buf_[len_++] = c;
        } else {
          // Overflow: drop current line to protect memory and resync.
          len_ = 0;
        }
      }
    }
    return false;
  }

private:
  static constexpr uint8_t MAX_ = 64; // keep this matched with parser expectations
  char   buf_[MAX_];
  uint8_t len_;
};

// ---------- Main application: parses commands & orchestrates everything ----------
class BusyLightApp {
public:
  BusyLightApp()
  : led_(cfg::NUM_LEDS, cfg::LED_PIN),
    hb_(cfg::HB_DEFAULT_ENABLED, cfg::HB_DEFAULT_TIMEOUT_MS) {}

  /* Initialize Serial, LED, heartbeat, and print a ready banner. */
  void begin() {
    Serial.begin(cfg::BAUD);
    led_.begin();
    led_.bootBlink();   // quick visual check that firmware is alive
    hb_.begin();        // start heartbeat timer window now
    Serial.println(F("BUSYLIGHT READY"));
  }

  /* Main loop: process serial input and heartbeat timeout. */
  void tick() {
    // 1) Handle any pending serial lines (non-blocking)
    const char* line = nullptr;
    while (reader_.readLine(Serial, line)) {
      processLine(line);
    }

    // 2) Heartbeat watchdog: auto-off when host stops pinging
    if (hb_.update()) {
      // Entered "timeout" state → turn LED off once.
      led_.forceOff();
      // Optional debug:
      // Serial.println(F("TIMEOUT"));
    }
  }

private:
  // ---- Parsing helpers ----

  /*
    Parse three integers from a C-string. Accepts whitespace-separated values.
    Clamps each channel to 0..255. Returns true on success.
  */
  static bool parseRGBTriplet(const char* s, int& r, int& g, int& b) {
    char* p;
    r = strtol(s, &p, 10); if (p == s) return false;  // no digits -> fail
    g = strtol(p, &p, 10);
    b = strtol(p, &p, 10);
    r = constrain(r, 0, 255);
    g = constrain(g, 0, 255);
    b = constrain(b, 0, 255);
    return true;
  }

  /* Tiny convenience to reply to PING. Also resets the heartbeat in cmd handler. */
  void replyPong() {
    Serial.println(F("PONG"));
  }

  // ---- Command handlers (each handles its own arguments) ----

  void cmdHBEN(const char* s) {
    const int v = atoi(s);            // "0" or "1" (anything nonzero -> true)
    hb_.setEnabled(v != 0);
    Serial.print(F("HBEN=")); Serial.println(hb_.enabled() ? 1 : 0);
  }

  void cmdHBENQ() {
    Serial.print("HBEN="); Serial.println(hb_.enabled() ? 1 : 0);
  }

  void cmdHBTO(const char* s) {
    long v = atol(s);
    hb_.setTimeout((uint32_t)v);
    Serial.print(F("HBTO=")); Serial.println(hb_.timeout());
  }

  void cmdHBTOQ() {
    Serial.print("HBTO=");
    Serial.println(hb_.timeoutMs());
  }

  void cmdHBRST() {
    hb_.reset();
    Serial.println(F("HBRST=OK"));
  }

  void cmdSTAT() {
    uint8_t r,g,b; led_.getRGB(r,g,b);
    Serial.print(F("STAT="));
    Serial.print(hb_.isTimedOut() ? F("TIMEOUT") : F("OK"));
    Serial.print(F("; RGB="));
    Serial.print(r); Serial.print(' ');
    Serial.print(g); Serial.print(' ');
    Serial.println(b);
  }

  void cmdVERQ() {
    Serial.print("VER="); Serial.print(VERSION);
    Serial.print("; BUILD="); Serial.print(__DATE__);   // "Jan  5 2026"
    Serial.print(" "); Serial.println(__TIME__); // "HH:MM:SS"
  }

  /*
    Parse and act on a single command line.
    Copy 'raw' into a small mutable buffer to safely trim/tokenize in place.
    Supported commands are described at the top of this file.
  */
  void processLine(const char* raw) {
    // Local buffer avoids modifying the caller's memory and keeps things bounded.
    char line[64];
    strncpy(line, raw, sizeof(line)-1);
    line[sizeof(line)-1] = 0;

    // Trim leading/trailing whitespace
    char* s = trimInPlace(line);
    if (!*s) return; // empty line after trimming

    // Extract first token (uppercased) for command matching
    char token[8] = {0};
    uint8_t i = 0;
    while (s[i] && !isSpaceC(s[i]) && i < sizeof(token)-1) {
      token[i] = (char)toupper(s[i]);
      i++;
    }
    token[i] = 0;

    // Advance pointer beyond the first token into "args"
    char* args = s + i;
    while (*args && isSpaceC(*args)) args++;

    // ---- Heartbeat / status commands ----
    if (!strcmp(token, "PING"))  { if (hb_.isTimedOut()) {led_.restoreDesired();}; hb_.ping(); replyPong(); return; }
    if (!strcmp(token, "HBEN"))  { cmdHBEN(args); return; }
    if (!strcmp(token, "HBEN?")) { cmdHBENQ(); return; }
    if (!strcmp(token, "HBTO"))  { cmdHBTO(args); return; }
    if (!strcmp(token, "HBTO?")) { cmdHBTOQ(); return; }
    if (!strcmp(token, "HBRST")) { if (hb_.isTimedOut()) {led_.restoreDesired();}; cmdHBRST(); return; }
    if (!strcmp(token, "STAT?")) { cmdSTAT(); return; }
    if (!strcmp(token, "VER?")) { cmdVERQ(); return; }

    // ---- Test / simple control ----
    if (!strcmp(token, "TEST"))  { led_.testPattern(); return; }
    if (!strcmp(token, "OFF"))   { led_.setRGB(0,0,0); return; }

    // "RGB r g b" form
    if (!strcmp(token, "RGB")) {
      int r,g,b;
      if (parseRGBTriplet(args, r, g, b)) {
        led_.setRGB((uint8_t)r,(uint8_t)g,(uint8_t)b);
        return;
      }
    }

    // Plain "r g b" form (no leading token)
    {
      int r,g,b;
      if (parseRGBTriplet(s, r, g, b)) {
        led_.setRGB((uint8_t)r,(uint8_t)g,(uint8_t)b);
        return;
      }
    }

    // Hex "#RRGGBB" form
    if (s[0] == '#' && strlen(s) == 7) {
      long v = strtol(s + 1, nullptr, 16);
      uint8_t r = (v >> 16) & 0xFF;
      uint8_t g = (v >> 8)  & 0xFF;
      uint8_t b = (v      ) & 0xFF;
      led_.setRGB(r,g,b);
      return;
    }

    // Unknown command → print a lightweight error and continue
    Serial.println(F("ERR"));
  }

private:
  NeoPixelLed       led_;     // hardware LED controller
  Heartbeat         hb_;      // heartbeat watchdog (auto-off)
  SerialLineReader  reader_;  // non-blocking line input
};

// ---------- Single hidden instance ----------
/*
  Avoid a global variable by using a function-local static. This guarantees
  a single instance for the lifetime of the program and defers initialization
  until first use (before setup()).
*/
static BusyLightApp& app() {
  static BusyLightApp instance;
  return instance;
}

// ---------- Arduino entry points ----------
void setup() { app().begin(); }
void loop()  { app().tick();  }

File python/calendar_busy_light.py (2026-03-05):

# Standard library
import ctypes
import json
import logging
import os
import subprocess
import sys
import time
import webbrowser
from datetime import datetime, timedelta
from logging.handlers import RotatingFileHandler
from typing import Optional, TypedDict, cast
from enum import IntEnum
from serial.tools import list_ports

# GUI (Tkinter)
import tkinter as tk
from tkinter import colorchooser as cc
from tkinter import messagebox, ttk

# Third-party
import serial  # pip install pyserial

# NOTE: Outlook COM (pywin32) is imported lazily where needed:
#   import win32com.client  # inside get_calendar_info()

# -----------------------------------------------------------------------------
# App / config paths
# -----------------------------------------------------------------------------
__version__ = "1.0.1"
APP_NAME = "CalendarBusyLight"
CONFIG_BASENAME = "calendar_busy_light_config.json"

def _config_path() -> str:
    appdata = os.getenv("APPDATA") or os.path.expanduser("~")
    cfg_dir = os.path.join(appdata, APP_NAME)
    os.makedirs(cfg_dir, exist_ok=True)
    return os.path.join(cfg_dir, CONFIG_BASENAME)

CONFIG_PATH = _config_path()

# -----------------------------------------------------------------------------
# Defaults
# -----------------------------------------------------------------------------
DEFAULT_COLORS = {
    "busy": [255, 0, 0],
    "upcoming_busy": [255, 64, 0],
    "free": [0, 255, 0],
    "oof": [0, 0, 0],
    "unknown": [0, 0, 0],
}

DEFAULT_CONFIG = {
    # per-status icon paths to .ico or .png; empty = default icon
    "status_icon_files": {  
        "busy": "./assets/busy.ico",
        "upcoming_busy": "./assets/upcoming_busy.ico",
        "free": "./assets/free.ico",
        "oof": "./assets/out_of_office.ico",
        "unknown": ""
    }, 

    # Serial / hardware
    "serial_port": "COM26",
    "baudrate": 115200,
    "simulate": False,
    "serial_retry_seconds": 5,

    # Timing
    "status_refresh_seconds": 15.0,
    "blink_period_seconds": 1.0,
    "gui_tick_ms": 100,

    # Calendar logic
    "upcoming_busy_minutes": 5,
    "past_grace_minutes": 1,
    "ignore_subjects": "",   # e.g. "lunch; focus; reminder"

    # Working hours
    "work_start_hour": 8,
    "work_start_minute": 0,
    "work_end_hour": 17,
    "work_end_minute": 0,
    "weekdays_only": True,
    "out_of_hours_status": "oof",  # "oof","free","busy","unknown"

    # Logging (UI booleans)
    "verbose_calendar": False,
    "show_status_summary": True,
    "log_color_changes": True,

    # Appearance
    "brightness_percent": 100,
    "fade_ms": 300,  # NOTE: 0 = instant

    # Color scheme
    "colors": DEFAULT_COLORS,

    # Heartbeat / ACK
    "heartbeat_enabled": True,
    "heartbeat_interval_seconds": 10,
    "heartbeat_expect_ack": False,   # set True if your Arduino answers
    "heartbeat_command": "PING",
    "heartbeat_response": "PONG",
    "heartbeat_timeout_ms": 500,

    # Quick Override (we now use this for BUSY-for-N-min)
    "quick_override_enabled": True,
    "quick_override_default_minutes": 15,  # used for Busy for N minutes
}

# Logging behavior defaults
LOG_DEFAULTS = {
    "log_level": "INFO",          # DEBUG, INFO, WARNING, ERROR
    "log_to_console": False,      # echo to console in addition to file
    "log_file_max_mb": 2,         # rotate after ~2 MB
    "log_file_backups": 5,        # keep 5 backups
}

# Module-level logger holder (populated in run())
LOGGER = logging.getLogger("busy_light")

# -----------------------------------------------------------------------------
# Config load / save
# -----------------------------------------------------------------------------
def load_config() -> dict:
    # deep copy defaults
    cfg = json.loads(json.dumps(DEFAULT_CONFIG))
    path = CONFIG_PATH
    if not os.path.exists(path):
        return cfg
    try:
        with open(path, "r", encoding="utf-8") as f:
            data = json.load(f)
        if isinstance(data, dict):
            for k, v in data.items():
                if k != "colors":
                    cfg[k] = v
            colors = cfg.get("colors", {}) or {}
            loaded_colors = data.get("colors", {})
            if not isinstance(loaded_colors, dict):
                loaded_colors = {}
            for key, default_rgb in DEFAULT_COLORS.items():
                rgb = loaded_colors.get(key, default_rgb)
                if not isinstance(rgb, (list, tuple)) or len(rgb) < 3:
                    rgb = default_rgb
                colors[key] = [max(0, min(255, int(x))) for x in rgb[:3]]
            cfg["colors"] = colors
    except Exception as e:
        print(f"Failed to load config from {path}, using defaults: {e}")
    return cfg

def save_config(config: dict) -> None:
    path = CONFIG_PATH
    # sanitize + deep copy
    safe_cfg = json.loads(json.dumps(config))
    colors = safe_cfg.get("colors", {}) or {}
    for k, rgb in colors.items():
        if not isinstance(rgb, (list, tuple)) or len(rgb) < 3:
            colors[k] = list(DEFAULT_COLORS.get(k, [0, 0, 0]))
        else:
            colors[k] = [max(0, min(255, int(x))) for x in rgb[:3]]
    safe_cfg["colors"] = colors

    tmp = path + ".tmp"
    try:
        with open(tmp, "w", encoding="utf-8") as f:
            json.dump(safe_cfg, f, indent=2)
        os.replace(tmp, path)  # atomic on Windows 10+
        print("Configuration saved to", path)
    except Exception as e:
        try:
            if os.path.exists(tmp):
                os.remove(tmp)
        except Exception:
            pass
        print("Failed to save config:", e)
# -----------------------------------------------------------------------------
# Helpers: that safely narrows the Meeting type before index it
# -----------------------------------------------------------------------------
class BusyStatus(IntEnum):
    """Outlook BusyStatus code (0=Free, 1=Tentative, 2=Busy, 3=OOF, 4=WorkingElsewhere)."""
    FREE = 0
    TENTATIVE = 1
    BUSY = 2
    OOF = 3
    WORKING_ELSEWHERE = 4
    UNKNOWN = 255  # fallback for unexpected values

def to_busy_status(value: int) -> BusyStatus:
    try:
        return BusyStatus(value)
    except ValueError:
        return BusyStatus.UNKNOWN
    
class Meeting(TypedDict):
    """Calendar meeting snapshot used by the GUI and LED logic.

    Fields:
        start: Local (naive) start time of the meeting.
        end:   Local (naive) end time of the meeting.
        subject: Subject/title text (may be empty).
        busy_status: Outlook BusyStatus code (0=Free, 1=Tentative, 2=Busy, 3=OOF, 4=WorkingElsewhere).
        location: Location text (may be empty).
    """
    start: datetime
    end: datetime
    subject: str
    busy_status: BusyStatus
    location: str
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

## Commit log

2025-12-22 fix(firmware): restore LED color after heartbeat timeout
    [busylight.ino]
2026-01-05 fix(python): resend last LED color after serial reconnect
    [calendar_busy_light.py]
2026-01-19 feat(python): serial auto-detect Busy Light COM port via PING/PONG fallback scan
    - Try the configured COM port first; if unavailable or unresponsive, scan all available ports
    - Probe each candidate with PING and require a PONG response before selecting it
    - Track and display the active (connected) port separately from the configured port
    - Improves resilience to Windows COM port renumbering and USB replug events
    On branch develop
    Changes to be committed:
    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

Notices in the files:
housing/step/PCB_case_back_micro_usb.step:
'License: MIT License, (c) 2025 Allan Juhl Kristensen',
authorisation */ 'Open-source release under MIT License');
